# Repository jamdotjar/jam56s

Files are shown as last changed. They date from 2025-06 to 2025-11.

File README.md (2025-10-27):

# jam56s
A 56-key hotswap column-staggered split keyboard.



*I'll replace this with a proper photo once it's built, but for now heres a quick render*

This is my first custom keyboard design, and my second hardware project. It was designed with a few goals in mind:
1. to be functional ( not broken, hard to break )
2. to be mine ( my own design, for my use case )
3. to be simple ( simple to use, simple to build )
4. to be something I'll actually use.

these were the basis of almost every decision I made while designing this. I chose a split layout because I already had a fairly nice 65% keyboard (the nuPhy air60 v2), I felt like anything too similar would fight for use (4). Secondly, I wanted to try and make a layout very personal to me, so this would be a truly from-scratch build (2). I used [ergopad](https://pashutk.com/ergopad/) to get a rough idea of what a good layout could be for me, then I used [ergogen](https://ergogen.xyz/) to quickly protoype my designs until I arrived at something I could copy in keycad. For the layout and physical design of the jam56s I took inspiration from the [lily58](https://github.com/kata0510/Lily58), the [Corne](https://github.com/foostan/crkbd), and the [ErgoTravel](https://github.com/jpconstantineau/ErgoTravel), among others. My main considerations were having enough keys for macros and modifiers, while not letting it get too big. The final layout is 6x(4-key column) + a 4 key thumb cluster. ( wired as a 7x4 matrix, see below )
wiring.



The board includes:
- Per-key RGB
- 1 I2C breakout ( for an OLED )
- RJ45 split comms
- Hot-swap sockets
I Chose an RJ45 jack over the more common TRRS jack as it can be safely hotplugged while the board is on. I didn't want to have to handle a USBC plug, which also seemed like overkill and ran the risk of frying the keeb if it was used for anything other than split comms.




The case is mostly 3D printed, but you can late lasercut for better asthetics and rigidity. This was my first time using fusion so it's just a little bit jank. It's kinda an open-air sorta sandiwch design, I mainly just wanted to always be able to see the PCB.

## BOM
In case you want to try to build this yourself, here's the prices I got for all the components. Prices are all in USD, even though I'm in Canada. ( also includes shipping )
| Item | Quantity | Price | Source | Additional details |
| --- | --- | --- | --- | --- |
| PCB | 2x5 | 39.99 | JLCPCB | 23.6 subtotal + 12.14 shipping + 4.25 tax |
| Plate | 2 | 35.67 | SendCutSend | I Might be able to get it for cheaper locally, or in a diff material |
| Orpheus Pico | 2 | N/A | Hack Club | Can be replaced with other USCB pico clone |
| Kailh hot-swap socket | 70 | 99c | Aliexpress | This is where the welcome deal seems to be placed right now |
| RJ45 Jacks | 2 | 2.63 | Aliexpress | |
| RJ45 cable | 1 | 1.72 | Aliexpress | |
| .91 in oled | 2.22 | Aliexpress | |
| 1n4148 diodes | 100 | 1.97 | Aliexpress | |
| 0805 0.1uf capacitor | 100 | 2.2 | Aliexpress | |
| SK6812mini-Es | 100 | 6.26 | Aliexpress | |
| TTC silent red or silent frozen | 60 | 32.7 | TorontoKeyboardMan | <alt pick is otemu silent yellow jade (0.22) or silent kitty (0.45)  |
| Keycaps | 140 |20.35 |Aliexpress |
| M2.5 x 25mm screw | 50 | 2.28 | Aliexpress | |
| M2.5x9mm spacer | 35 | 2.78 | Aliexpres | can also be 3d printed |
| Total | 1 | 149.54 | ||

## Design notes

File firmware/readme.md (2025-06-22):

# jam56s

jam56s

*A short description of the keyboard/project*

* Keyboard Maintainer: [jamdotjar](https://github.com/jamdotjar)
* Hardware Supported: *The PCBs, controllers supported*
* Hardware Availability: *Links to where you can find this hardware*

Make example for this keyboard (after setting up your build environment):

    make jam56s:default

Flashing example for this keyboard:

    make jam56s:default:flash

See the [build environment setup](https://docs.qmk.fm/#/getting_started_build_tools) and the [make instructions](https://docs.qmk.fm/#/getting_started_make_guide) for more information. Brand new to QMK? Start with our [Complete Newbs Guide](https://docs.qmk.fm/#/newbs).

## Bootloader

Enter the bootloader in 3 ways:

* **Bootmagic reset**: Hold down the key at (0,0) in the matrix (usually the top left key or Escape) and plug in the keyboard
* **Physical reset button**: Briefly press the button on the back of the PCB - some may have pads you must short instead
* **Keycode in layout**: Press the key mapped to `QK_BOOT` if it is available

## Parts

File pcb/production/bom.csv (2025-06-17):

Designator | Footprint | Quantity | Value | LCSC Part #
C29, C30, C31, C32, C33, C34, C35, C36, C37, C38, C39, C40, C41, C42, C43, C44, C45, C46, C47, C48, C49, C50, C51, C52, C53, C54, C55, C56 | 0805 | 28 | C
D1, D10, D11, D12, D17, D18, D19, D2, D20, D25, D26, D27, D28, D3, D33, D34, D35, D36, D4, D41, D42, D43, D44, D49, D50, D51, D52, D9 | Diode | 28 | D
D101, D102, D103, D104, D110, D111, D112, D113, D58, D59, D64, D65, D66, D67, D68, D73, D74, D75, D76, D77, D82, D83, D84, D85, D86, D92, D93, D94, D95 | LED_6028R | 29 | SK6812MINI
D57 | D_DO-35_SOD27_P7.62mm_Horizontal | 1 | 1N4148
J3 | RJ45_Amphenol_54602-x08_Horizontal | 1 | RJ45
S1, S10, S11, S12, S17, S18, S19, S2, S20, S25, S26, S27, S28, S3, S33, S34, S35, S36, S4, S41, S42, S43, S44, S49, S50, S51, S52, S9 | MX-Hotswap-1U | 28 | SW_Push_45deg
U2 | RaspberryPi_Pico_Common_THT | 1 | Pico

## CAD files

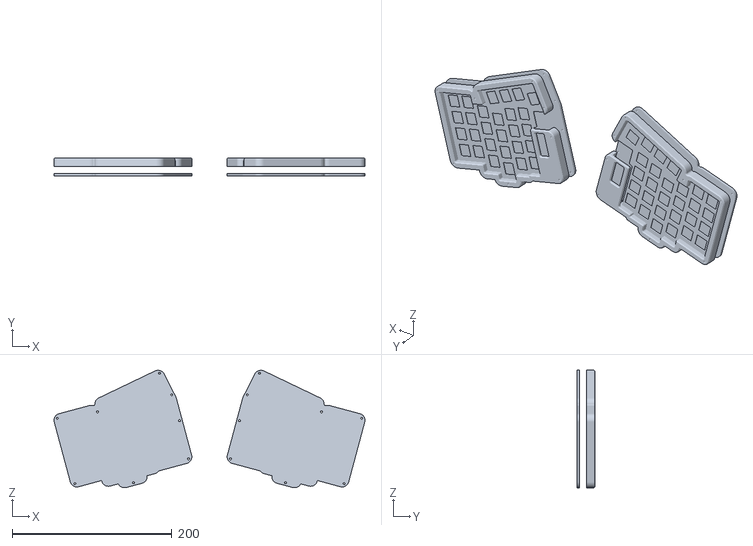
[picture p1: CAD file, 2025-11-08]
production/jamboard_full.stl
389.2 x 22.5 x 147.1

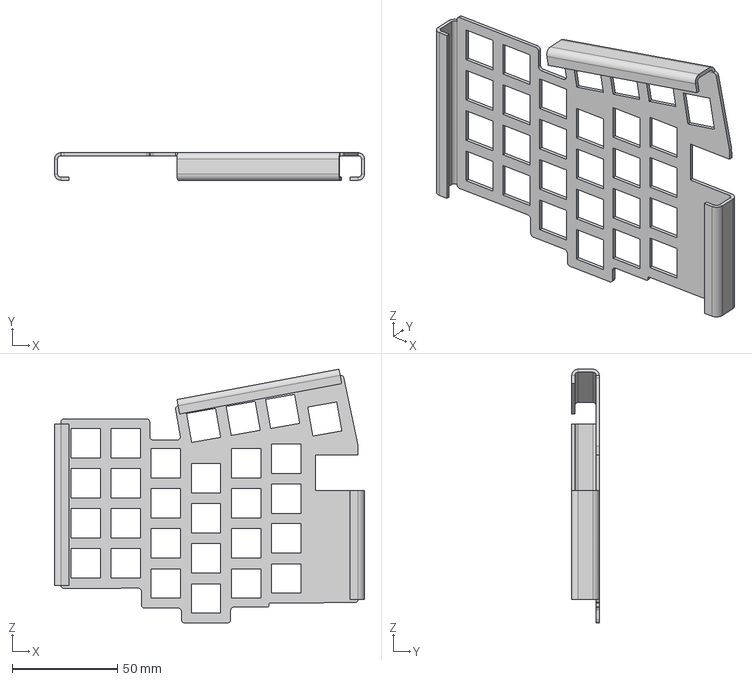
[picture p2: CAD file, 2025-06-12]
cad/Untitled.step
147.5 x 13.1 x 120.7 mm

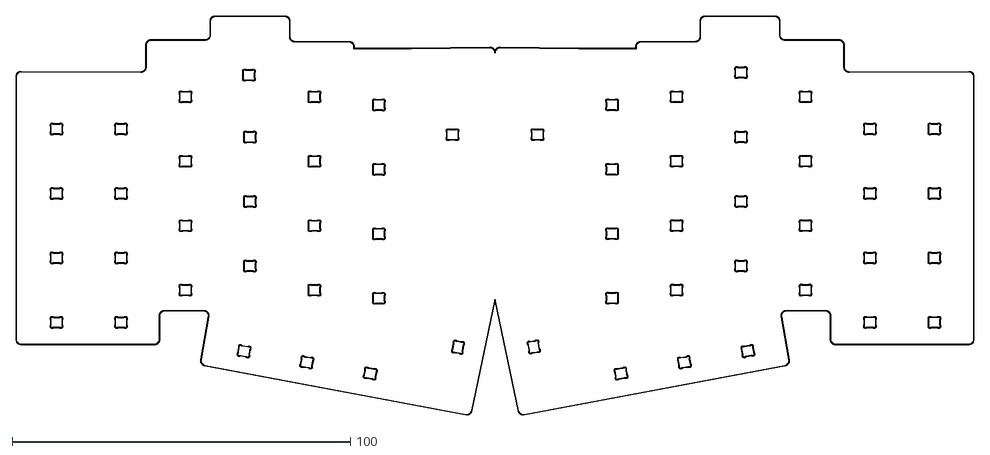
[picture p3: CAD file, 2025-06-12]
pcb/jamboard-Edge_Cuts.dxf
283.0 x 117.8

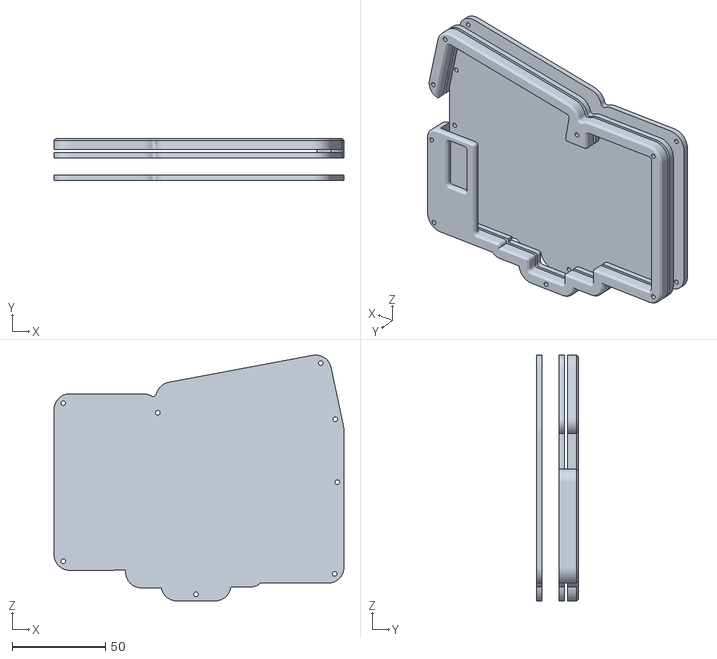
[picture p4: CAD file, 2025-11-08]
production/Jamboard half 3dp.stl
155.4 x 22.5 x 131.7

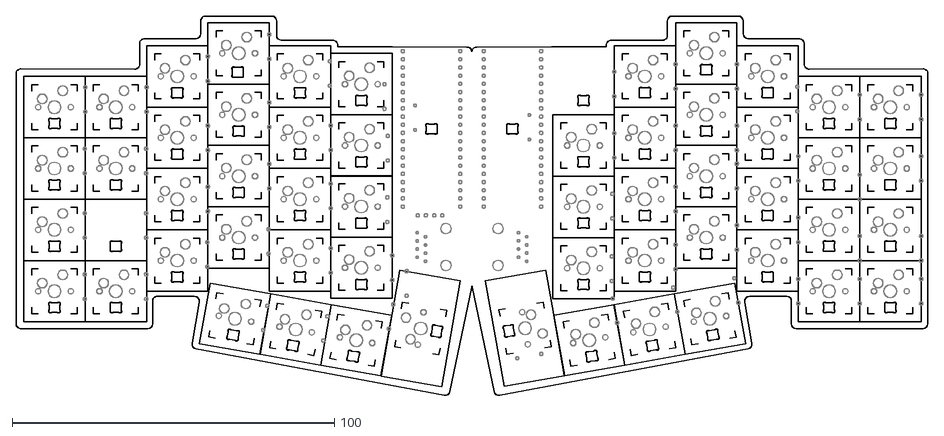
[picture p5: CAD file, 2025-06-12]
pcb/jamboard-User_Drawings.dxf
283.0 x 117.9

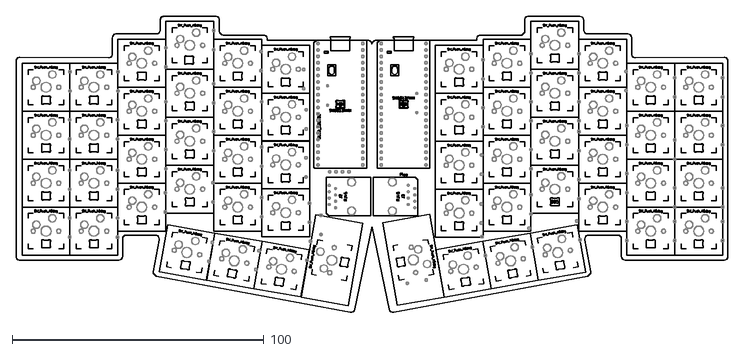
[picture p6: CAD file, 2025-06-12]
pcb/jamboard-F_Fab.dxf
283.0 x 117.9

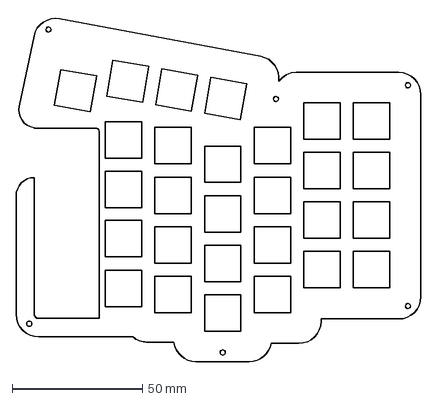
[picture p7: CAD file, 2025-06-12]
production/plate.dxf
155.4 x 132.5 mm

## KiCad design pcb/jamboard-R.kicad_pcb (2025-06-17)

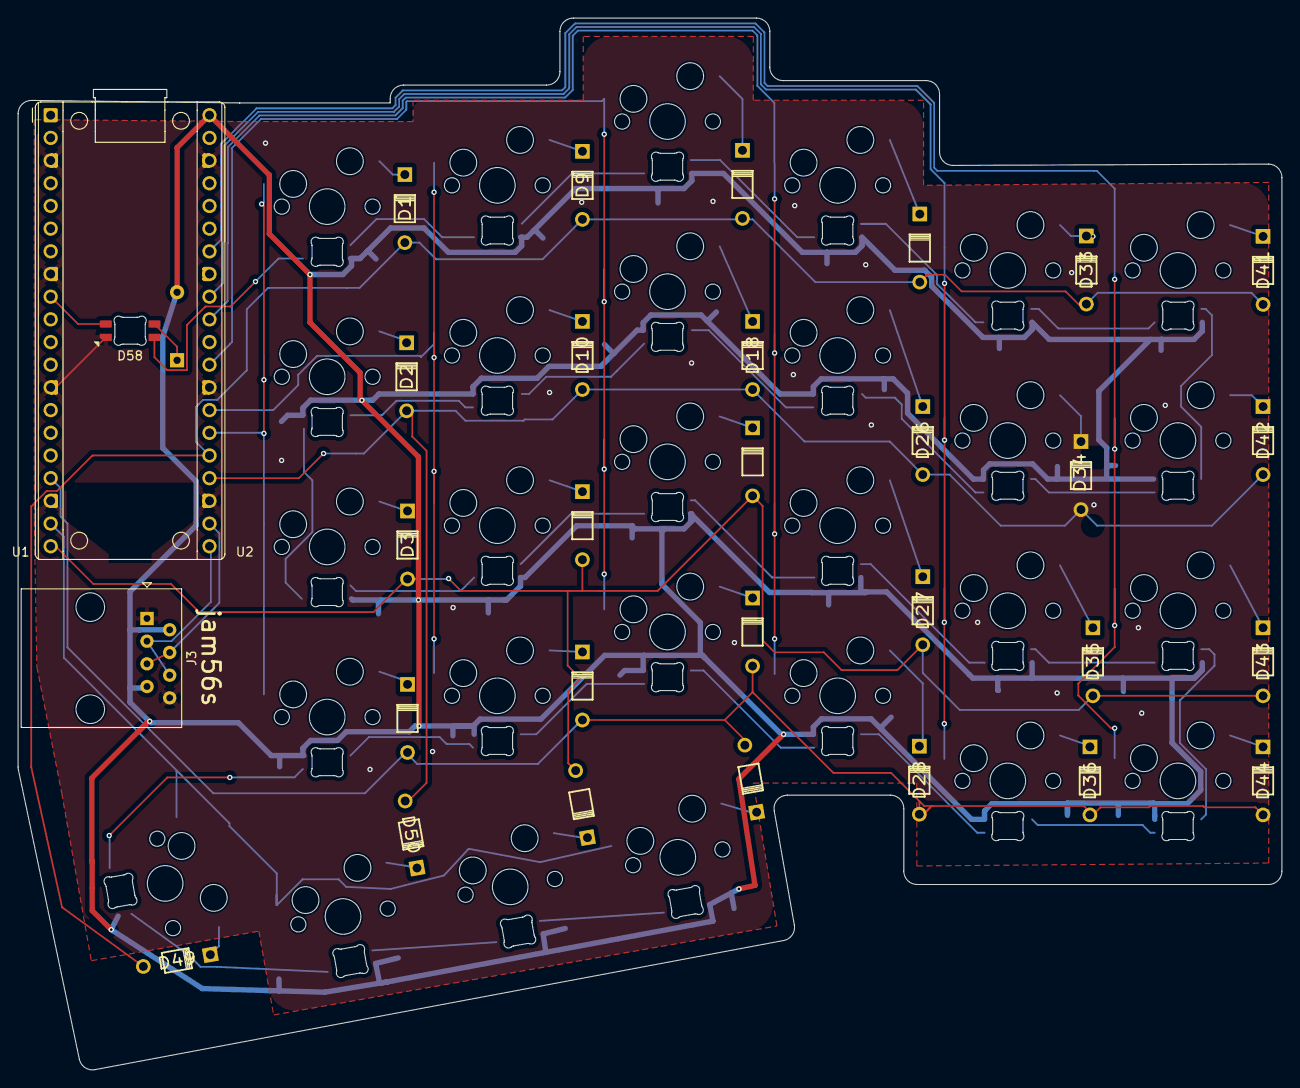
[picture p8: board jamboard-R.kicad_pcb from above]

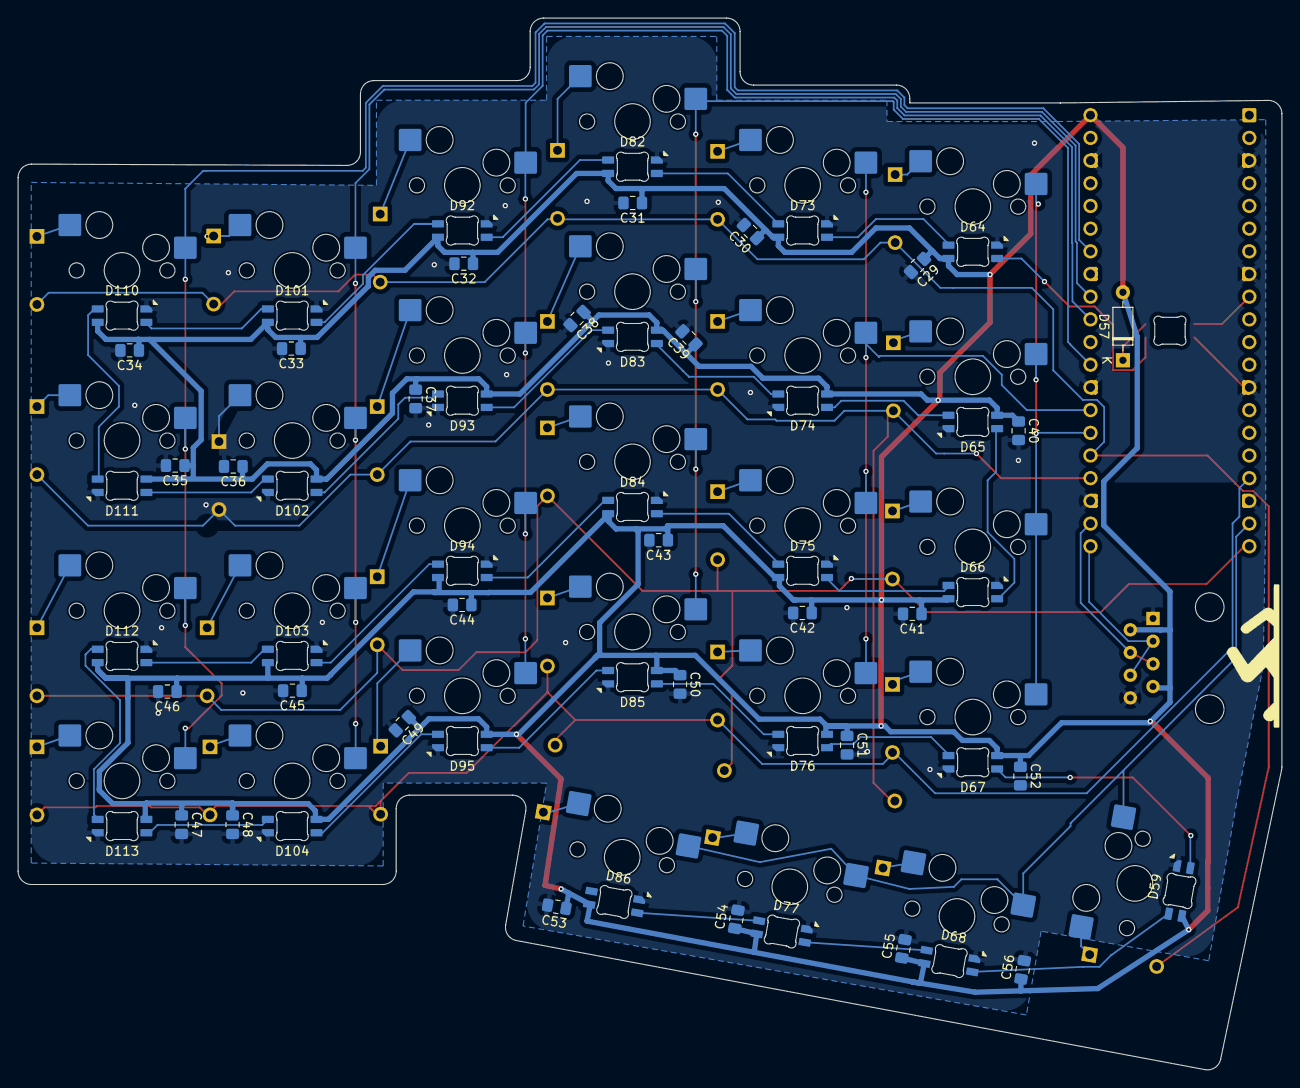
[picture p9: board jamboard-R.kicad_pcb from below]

Board: 2 copper layers, 141.5 x 117.8 mm, 116 parts (85 on the bottom side), 73 nets.

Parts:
C29, C30, C31, C32, C33, C34, C35, C36, C37, C38, C39, C40, C41, C42, C43, C44, C45, C46, C47, C48, C49, C50, C51, C52, C53, C54, C55, C56: C; C_0805_2012Metric_Pad1.18x1.45mm_HandSolder
D1, D2, D3, D4, D9, D10, D11, D12, D17, D18, D19, D20, D25, D26, D27, D28, D33, D34, D35, D36, D41, D42, D43, D44, D49, D50, D51, D52: D; Diode
D57: 1N4148; D_DO-35_SOD27_P7.62mm_Horizontal
D58, D59, D64, D65, D66, D67, D68, D73, D74, D75, D76, D77, D82, D83, D84, D85, D86, D92, D93, D94, D95, D101, D102, D103, D104, D110, D111, D112, D113: SK6812MINI; LED_6028R
J3: RJ45; RJ45_Amphenol_54602-x08_Horizontal
S1, S2, S3, S4, S9, S10, S11, S12, S17, S18, S19, S20, S25, S26, S27, S28, S33, S34, S35, S36, S41, S42, S43, S44, S49, S50, S51, S52: SW_Push_45deg; MX-Hotswap-1U
U2: Pico; RaspberryPi_Pico_Common_THT

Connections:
+5V: C29.1, C30.1, C31.1, C32.1, C33.1, C34.1, C35.1, C36.1, C37.1, C38.1, C39.1, C40.1, C41.1, C42.1, C43.1, C44.1, C45.1, C46.1, C47.1, C48.1, C49.1, C50.1, C51.1, C52.1, C53.1, C54.1, C55.1, C56.1, D57.2 (A), D59.1 (VDD), D64.1 (VDD), D65.1 (VDD), D66.1 (VDD), D67.1 (VDD), D68.1 (VDD), D73.1 (VDD), D74.1 (VDD), D75.1 (VDD), D76.1 (VDD), D77.1 (VDD), D82.1 (VDD), D83.1 (VDD), D84.1 (VDD), D85.1 (VDD), D86.1 (VDD), D92.1 (VDD), D93.1 (VDD), D94.1 (VDD), D95.1 (VDD), D101.1 (VDD), D102.1 (VDD), D103.1 (VDD), D104.1 (VDD), D110.1 (VDD), D111.1 (VDD), D112.1 (VDD), D113.1 (VDD), J3.2, J3.7, U2.40 (VBUS)
GND: C29.2, C30.2, C31.2, C32.2, C33.2, C34.2, C35.2, C36.2, C37.2, C38.2, C39.2, C40.2, C41.2, C42.2, C43.2, C44.2, C45.2, C46.2, C47.2, C48.2, C49.2, C50.2, C51.2, C52.2, C53.2, C54.2, C55.2, C56.2, D58.4 (VSS), D59.4 (VSS), D64.4 (VSS), D65.4 (VSS), D66.4 (VSS), D67.4 (VSS), D68.4 (VSS), D73.4 (VSS), D74.4 (VSS), D75.4 (VSS), D76.4 (VSS), D77.4 (VSS), D82.4 (VSS), D83.4 (VSS), D84.4 (VSS), D85.4 (VSS), D86.4 (VSS), D92.4 (VSS), D93.4 (VSS), D94.4 (VSS), D95.4 (VSS), D101.4 (VSS), D102.4 (VSS), D103.4 (VSS), D104.4 (VSS), D110.4 (VSS), D111.4 (VSS), D112.4 (VSS), D113.4 (VSS), J3.1, J3.8, U2.3 (GND), U2.8 (GND), U2.13 (GND), U2.18 (GND), U2.23 (GND), U2.28 (GND), U2.38 (GND)
LED_DATA_R: D58.3 (DIN), U2.9 (GPIO6)
LinkA_R: J3.3, J3.6, U2.21 (GPIO16)
LinkB_R: J3.4, J3.5, U2.22 (GPIO17)
unnamed: D1.2 (A), S1.2
unnamed: D2.2 (A), S2.2
unnamed: D3.2 (A), S3.2
unnamed: D4.2 (A), S4.2
unnamed: D9.2 (A), S9.2
unnamed: D10.2 (A), S10.2
unnamed: D11.2 (A), S11.2
unnamed: D12.2 (A), S12.2
unnamed: D17.2 (A), S17.2
unnamed: D18.2 (A), S18.2
unnamed: D19.2 (A), S19.2
unnamed: D20.2 (A), S20.2
unnamed: D25.2 (A), S25.2
unnamed: D26.2 (A), S26.2
unnamed: D27.2 (A), S27.2
unnamed: D28.2 (A), S28.2
unnamed: D33.2 (A), S33.2
unnamed: D34.2 (A), S34.2
unnamed: D35.2 (A), S35.2
unnamed: D36.2 (A), S36.2
unnamed: D41.2 (A), S41.2
unnamed: D42.2 (A), S42.2
unnamed: D43.2 (A), S43.2
unnamed: D44.2 (A), S44.2
unnamed: D49.2 (A), S49.2
unnamed: D50.2 (A), S50.2
unnamed: D51.2 (A), S51.2
unnamed: D52.2 (A), S52.2
unnamed: D57.1 (K), D58.1 (VDD)
unnamed: D58.2 (DOUT), D64.3 (DIN)
unnamed: D59.3 (DIN), D67.2 (DOUT)
unnamed: D59.2 (DOUT), D68.3 (DIN)
unnamed: D64.2 (DOUT), D73.3 (DIN)
unnamed: D65.3 (DIN), D74.2 (DOUT)
unnamed: D65.2 (DOUT), D66.3 (DIN)
unnamed: D66.2 (DOUT), D75.3 (DIN)
unnamed: D67.3 (DIN), D76.2 (DOUT)
unnamed: D68.2 (DOUT), D77.3 (DIN)
unnamed: D73.2 (DOUT), D82.3 (DIN)
unnamed: D74.3 (DIN), D83.2 (DOUT)
unnamed: D75.2 (DOUT), D84.3 (DIN)
unnamed: D76.3 (DIN), D85.2 (DOUT)
unnamed: D77.2 (DOUT), D86.3 (DIN)
unnamed: D82.2 (DOUT), D92.3 (DIN)
unnamed: D83.3 (DIN), D93.2 (DOUT)
unnamed: D84.2 (DOUT), D94.3 (DIN)
unnamed: D85.3 (DIN), D95.2 (DOUT)
unnamed: D92.2 (DOUT), D101.3 (DIN)
unnamed: D101.2 (DOUT), D110.3 (DIN)
unnamed: D102.3 (DIN), D111.2 (DOUT)
unnamed: D93.3 (DIN), D102.2 (DOUT)
unnamed: D94.2 (DOUT), D103.3 (DIN)
unnamed: D103.2 (DOUT), D112.3 (DIN)
unnamed: D104.3 (DIN), D113.2 (DOUT)
unnamed: D95.3 (DIN), D104.2 (DOUT)
unnamed: D110.2 (DOUT), D111.3 (DIN)
unnamed: D112.2 (DOUT), D113.3 (DIN)
R_MATRIX COL 0: S1.1, S2.1, S3.1, S4.1, U2.26 (GPIO20)
R_MATRIX COL 1: S9.1, S10.1, S11.1, S12.1, U2.27 (GPIO21)
R_MATRIX COL 2: S17.1, S18.1, S19.1, S20.1, U2.29 (GPIO22)
R_MATRIX COL 3: S25.1, S26.1, S27.1, S28.1, U2.31 (GPIO26_ADC0)
R_MATRIX COL 4: S33.1, S34.1, S35.1, S36.1, U2.32 (GPIO27_ADC1)
R_MATRIX COL 5: S41.1, S42.1, S43.1, S44.1, U2.34 (GPIO28_ADC2)
R_MATRIX COL 6: S49.1, S50.1, S51.1, S52.1, U2.19 (GPIO14)
R_MATRIX ROW 0: D1.1 (K), D9.1 (K), D17.1 (K), D25.1 (K), D33.1 (K), D41.1 (K), D49.1 (K), U2.25 (GPIO19)
R_MATRIX ROW 1: D2.1 (K), D10.1 (K), D18.1 (K), D26.1 (K), D34.1 (K), D42.1 (K), D50.1 (K), U2.24 (GPIO18)
R_MATRIX ROW 2: D3.1 (K), D11.1 (K), D19.1 (K), D27.1 (K), D35.1 (K), D43.1 (K), D51.1 (K), U2.20 (GPIO15)
R_MATRIX ROW 3: D4.1 (K), D12.1 (K), D20.1 (K), D28.1 (K), D36.1 (K), D44.1 (K), D52.1 (K), U2.17 (GPIO13)

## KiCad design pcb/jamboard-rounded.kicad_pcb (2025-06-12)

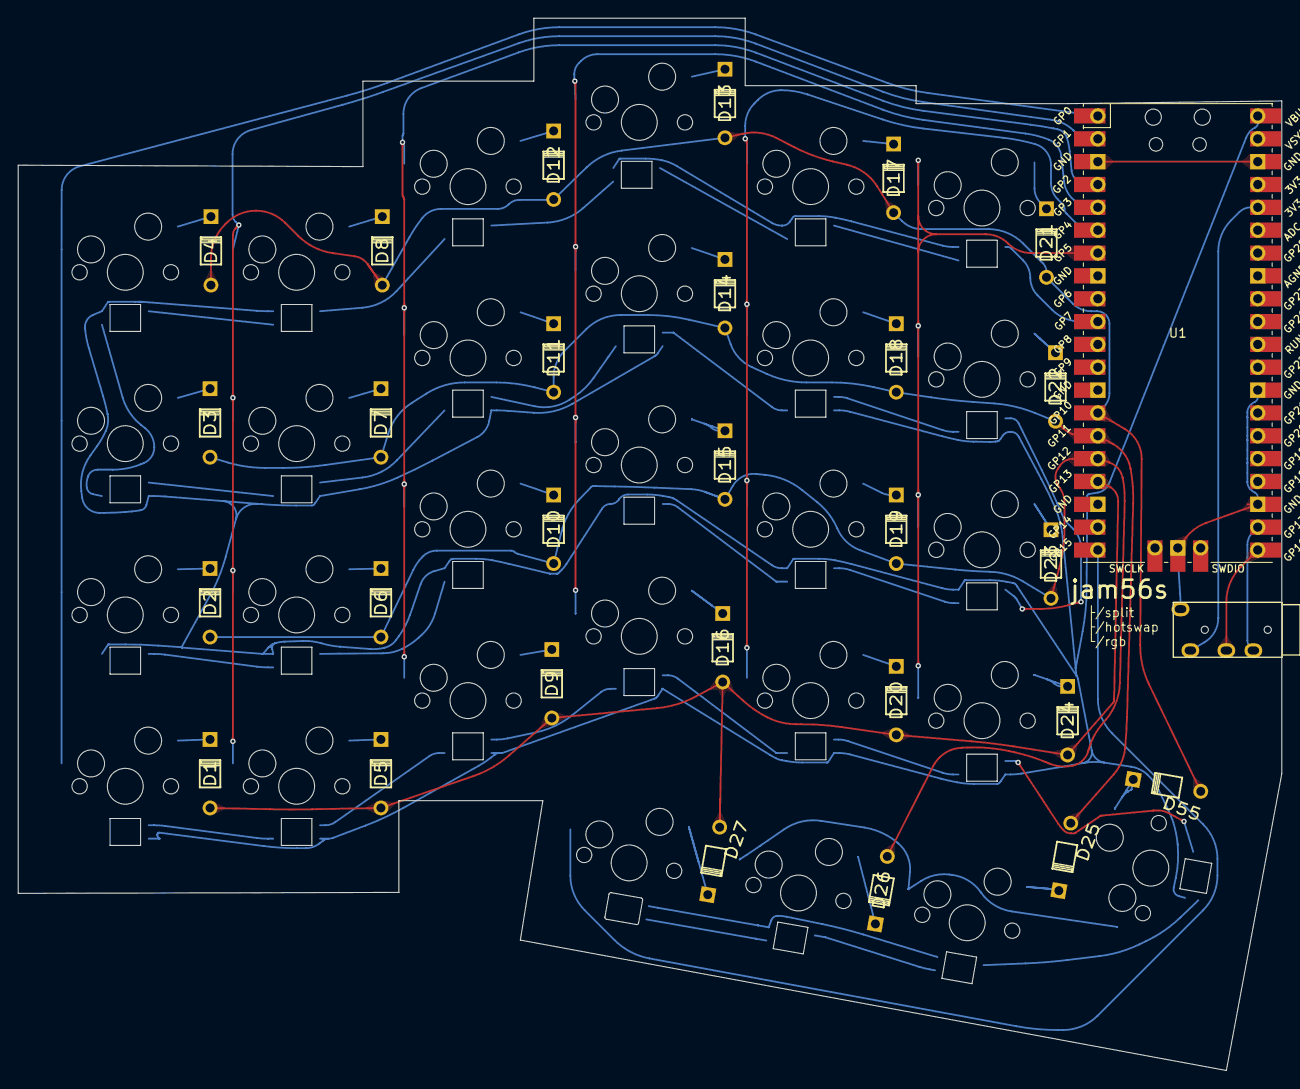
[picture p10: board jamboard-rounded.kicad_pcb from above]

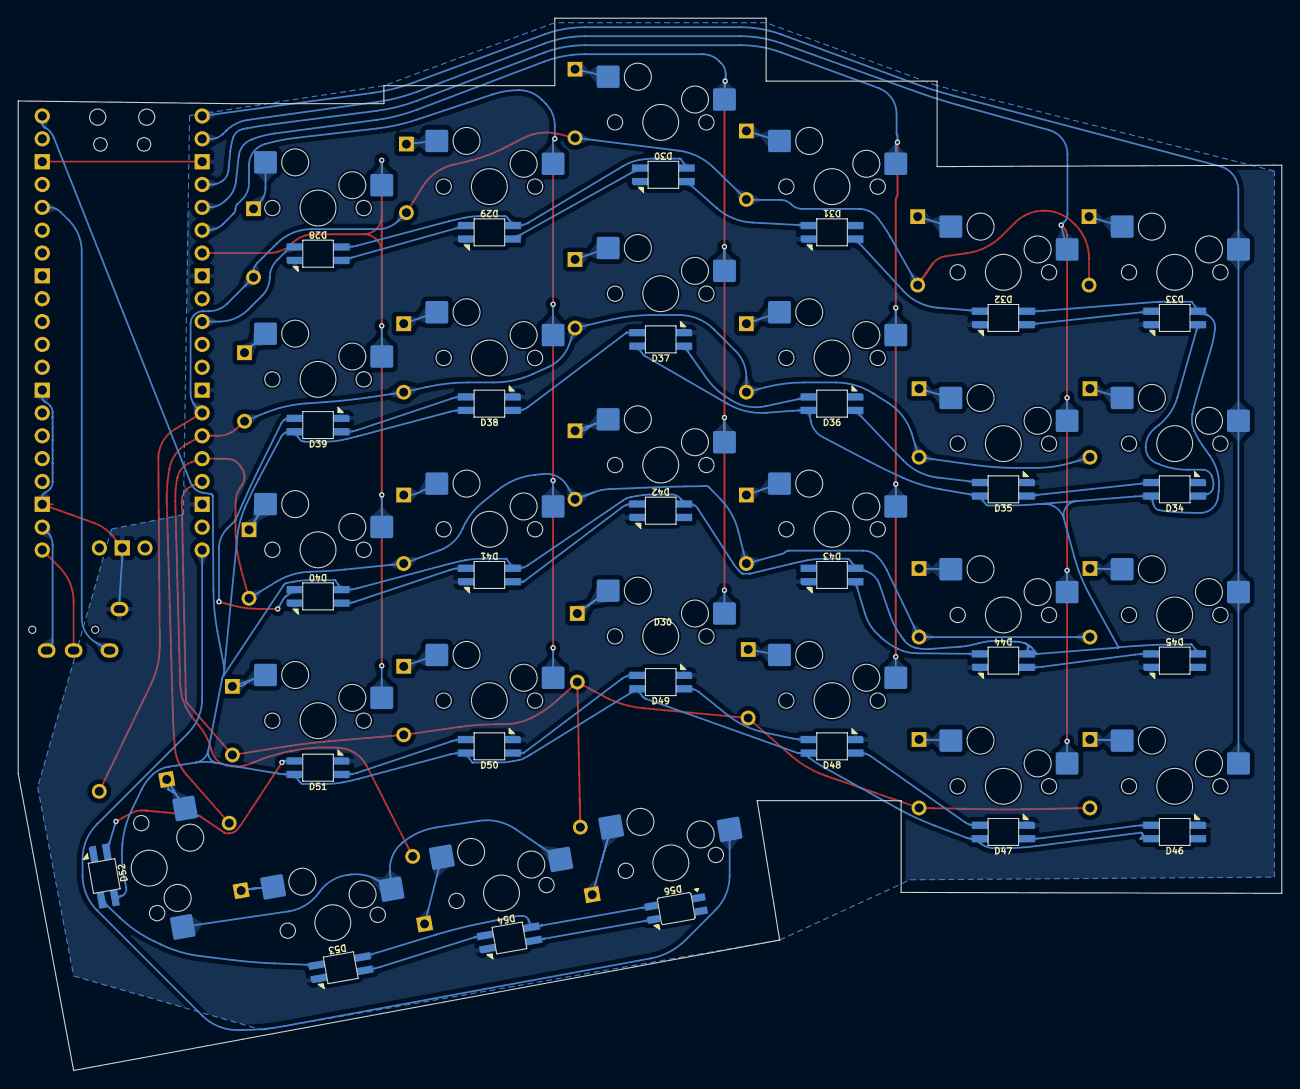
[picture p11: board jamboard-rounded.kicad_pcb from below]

Board: 2 copper layers, 140.5 x 117.0 mm, 86 parts (56 on the bottom side), 72 nets.

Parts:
D1, D2, D3, D4, D5, D6, D7, D8, D9, D10, D11, D12, D13, D14, D15, D16, D17, D18, D19, D20, D21, D22, D23, D24, D25, D26, D27, D55: D; Diode
D28, D29, D30, D31, D32, D33, D34, D35, D36, D37, D38, D39, D40, D41, D42, D43, D44, D45, D46, D47, D48, D49, D50, D51, D52, D53, D54: SK6812MINI; SK6812MINI-E
D56: SK6812MINI; SK6812-MINI-E
S1, S2, S3, S4, S5, S6, S7, S8, S9, S10, S11, S12, S13, S14, S15, S16, S17, S18, S19, S20, S21, S22, S23, S24, S25, S26, S27, S28: SW_Push_45deg; MX-Hotswap-1U
U1: Pico; RPi_Pico_SMD_TH
U2: TRRS; TRRS-PJ-320A

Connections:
+3V3: U1.36 (3V3), U2.2 (TIP)
+5V: D28.4 (VDD), D29.4 (VDD), D30.4 (VDD), D31.4 (VDD), D32.4 (VDD), D33.4 (VDD), D34.4 (VDD), D35.4 (VDD), D36.4 (VDD), D37.4 (VDD), D38.4 (VDD), D39.4 (VDD), D40.4 (VDD), D41.4 (VDD), D42.4 (VDD), D43.4 (VDD), D44.4 (VDD), D45.4 (VDD), D46.4 (VDD), D47.4 (VDD), D48.4 (VDD), D49.4 (VDD), D50.4 (VDD), D51.4 (VDD), D52.4 (VDD), D53.4 (VDD), D54.4 (VDD), D56.4 (VDD), U1.40 (VBUS)
GND: D28.2 (VSS), D29.2 (VSS), D30.2 (VSS), D31.2 (VSS), D32.2 (VSS), D33.2 (VSS), D34.2 (VSS), D35.2 (VSS), D36.2 (VSS), D37.2 (VSS), D38.2 (VSS), D39.2 (VSS), D40.2 (VSS), D41.2 (VSS), D42.2 (VSS), D43.2 (VSS), D44.2 (VSS), D45.2 (VSS), D46.2 (VSS), D47.2 (VSS), D48.2 (VSS), D49.2 (VSS), D50.2 (VSS), D51.2 (VSS), D52.2 (VSS), D53.2 (VSS), D54.2 (VSS), D56.2 (VSS), U1.3 (GND), U1.8 (GND), U1.13 (GND), U1.18 (GND), U1.23 (GND), U1.28 (GND), U1.38 (GND), U1.42 (GND), U2.1 (SLEEVE)
LED ROW 2: D33.1 (DOUT), D34.3 (DIN)
LED ROW 3: D40.1 (DOUT), D41.3 (DIN)
LED ROW 4: D47.1 (DOUT), D48.3 (DIN)
LED_ROW1: D28.3 (DIN), U1.10 (GPIO7)
MATRIX COL 0: S1.1, S2.1, S3.1, S4.1, U1.1 (GPIO0)
MATRIX COL 1: S5.1, S6.1, S7.1, S8.1, U1.2 (GPIO1)
MATRIX COL 2: S9.1, S10.1, S11.1, S12.1, U1.4 (GPIO2)
MATRIX COL 3: S13.1, S14.1, S15.1, S16.1, U1.5 (GPIO3)
MATRIX COL 4: S17.1, S18.1, S19.1, S20.1, U1.6 (GPIO4)
MATRIX COL 5: S21.1, S22.1, S23.1, S24.1, U1.7 (GPIO5)
MATRIX COL 6: S25.1, S26.1, S27.1, S28.1, U1.20 (GPIO15)
MATRIX ROW 0: D4.1 (K), D8.1 (K), D12.1 (K), D13.1 (K), D17.1 (K), D21.1 (K), D55.1 (K), U1.14 (GPIO10)
MATRIX ROW 1: D3.1 (K), D7.1 (K), D11.1 (K), D14.1 (K), D18.1 (K), D22.1 (K), D25.1 (K), U1.15 (GPIO11)
MATRIX ROW 2: D2.1 (K), D6.1 (K), D10.1 (K), D15.1 (K), D19.1 (K), D23.1 (K), D26.1 (K), U1.16 (GPIO12)
MATRIX ROW 3: D1.1 (K), D5.1 (K), D9.1 (K), D16.1 (K), D20.1 (K), D24.1 (K), D27.1 (K), U1.17 (GPIO13)
unnamed: D1.2 (A), S1.2
unnamed: D2.2 (A), S2.2
unnamed: D3.2 (A), S3.2
unnamed: D4.2 (A), S4.2
unnamed: D5.2 (A), S5.2
unnamed: D6.2 (A), S6.2
unnamed: D7.2 (A), S7.2
unnamed: D8.2 (A), S8.2
unnamed: D9.2 (A), S9.2
unnamed: D10.2 (A), S10.2
unnamed: D11.2 (A), S11.2
unnamed: D12.2 (A), S12.2
unnamed: D13.2 (A), S16.2
unnamed: D14.2 (A), S15.2
unnamed: D15.2 (A), S14.2
unnamed: D16.2 (A), S13.2
unnamed: D17.2 (A), S20.2
unnamed: D18.2 (A), S19.2
unnamed: D19.2 (A), S18.2
unnamed: D20.2 (A), S17.2
unnamed: D21.2 (A), S24.2
unnamed: D22.2 (A), S23.2
unnamed: D23.2 (A), S22.2
unnamed: D24.2 (A), S21.2
unnamed: D25.2 (A), S27.2
unnamed: D26.2 (A), S26.2
unnamed: D27.2 (A), S25.2
unnamed: D28.1 (DOUT), D29.3 (DIN)
unnamed: D29.1 (DOUT), D30.3 (DIN)
unnamed: D30.1 (DOUT), D31.3 (DIN)
unnamed: D31.1 (DOUT), D32.3 (DIN)
unnamed: D32.1 (DOUT), D33.3 (DIN)
unnamed: D34.1 (DOUT), D35.3 (DIN)
unnamed: D35.1 (DOUT), D36.3 (DIN)
unnamed: D36.1 (DOUT), D37.3 (DIN)
unnamed: D37.1 (DOUT), D38.3 (DIN)
unnamed: D38.1 (DOUT), D39.3 (DIN)
unnamed: D39.1 (DOUT), D40.3 (DIN)
unnamed: D41.1 (DOUT), D42.3 (DIN)
unnamed: D42.1 (DOUT), D43.3 (DIN)
unnamed: D43.1 (DOUT), D44.3 (DIN)
unnamed: D44.1 (DOUT), D45.3 (DIN)
unnamed: D45.1 (DOUT), D46.3 (DIN)
unnamed: D46.1 (DOUT), D47.3 (DIN)
unnamed: D48.1 (DOUT), D49.3 (DIN)
unnamed: D49.1 (DOUT), D50.3 (DIN)
unnamed: D50.1 (DOUT), D51.3 (DIN)
unnamed: D51.1 (DOUT), D52.3 (DIN)
unnamed: D52.1 (DOUT), D53.3 (DIN)
unnamed: D53.1 (DOUT), D54.3 (DIN)
unnamed: D54.1 (DOUT), D56.3 (DIN)
unnamed: D55.2 (A), S28.2
unnamed: U1.21 (GPIO16), U2.3 (RING1)
unnamed: U1.22 (GPIO17), U2.4 (RING2)

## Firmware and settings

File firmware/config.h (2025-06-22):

#define SERIAL_USART_FULL_DUPLEX // Enable full duplex operation mode.
#define SERIAL_USART_TX_PIN GP16
#define SERIAL_USART_RX_PIN GP17
#define SERIAL_PIO_USE_PIO1 // Force the usage of PIO1 peripheral, by default the Serial implementation uses the PIO0 peripheral
#define MASTER_LEFT
#define MATRIX_ROW_PINS_LEFT  { GP7, GP8, GP9, GP10 }
#define MATRIX_ROW_PINS_RIGHT { GP19, GP18, GP15, GP13 } 
#define MATRIX_COL_PINS_LEFT { GP0, GP1, GP2, GP3, GP4, GP15 }
#define MATRIX_COL_PINS_RIGHT { GP20, GP21, GP22, GP26, GP27, GP28 }

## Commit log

2025-06-12 inital commit
    [Untitled.step, bom.csv, designators.csv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]
2025-06-17 worked on readme
    [bom.csv, designators.csv, jamboard-L.kicad_pcb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]
2025-06-22 finialized BOM
2025-10-27 added BOM.csv
    [bom.csv]
2025-10-27 rust firmware attempt1
    [jamboard-L.kicad_pcb]
2025-10-27 Update README.md
    Updated BOM section to clarify that prices include shipping.
2025-11-08 organzied production assets
    [Jamboard half 3dp.stl, jamboard_full.stl, plate.dxf]
